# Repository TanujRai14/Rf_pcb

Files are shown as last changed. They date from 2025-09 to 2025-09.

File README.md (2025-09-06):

📡 STM32 + nRF24L01P USB Dongle (4-Layer PCB)

This project implements a USB-based transceiver dongle using the STM32L432 MCU and nRF24L01P RF module.
The board is designed as a 4-layer PCB optimized for USB high-speed signaling and RF performance.

🔧 Features

MCU: STM32L432KBU6 (Cortex-M4, USB support, low-power).

RF Transceiver: nRF24L01P with SMA antenna connector.

USB Interface: Micro USB-B with ESD protection.

Power Regulation: Onboard 3.3V regulator with USB +5V input.

Programming & Debugging: SWD connector for firmware upload/debug.

Clocking: 16 MHz crystal oscillator for the transceiver.

⚡️ PCB Design Notes

This design follows best practices for mixed-signal (USB + RF) high-speed boards:

4-Layer Stackup

Layer 1: Signal

Layer 2: Ground plane

Layer 3: Power plane + signal

Layer 4: Signal

➝ Provides controlled impedance routing and solid ground return paths.

USB Differential Pair

Routed as 90 Ω differential impedance.

Length matched using squiggle traces for proper signal timing.

Minimal via usage to reduce reflections.

Crystal Oscillator

No ground plane directly beneath the crystal to avoid damping oscillations.

RF Section

50 Ω controlled impedance routing to the SMA connector.

Antenna matching network (L-C components) placed close to RF pin.

Short traces and minimized via count for RF integrity.

Decoupling & Power Integrity

Multiple ceramic capacitors (100nF, 1µF, 10µF) placed near VDD pins.

Bulk capacitor on regulator output for stability.

Power traces kept short and wide to reduce IR drop.

Grounding

Continuous solid GND plane on Layer 2.

Stitching vias placed around high-speed and RF sections.

Segregation of analog/RF and digital sections to reduce noise coupling.

Other Notes

ESD protection diodes added on USB lines.

Reset capacitor for parasitic reset protection.

Careful placement of SWD pins for easy programming access.

🚀 Getting Started

Connect the board via USB Micro-B cable.

Flash firmware via SWD programmer (ST-Link, J-Link, etc.).

Use the USB interface for communication and debugging.

Attach an SMA antenna to nRF24L01P for wireless operation.

📌 To-Do / Future Improvements

 Add test points for power rails.

 Consider shielding can for RF section.

 Explore USB Type-C instead of Micro-B.

 Improve thermal relief on regulator section.

👤 Designer: Tanuj Rai
🛠 Tools Used: KiCad (schematic & PCB), 4-layer controlled impedance design.# Rf_pcb

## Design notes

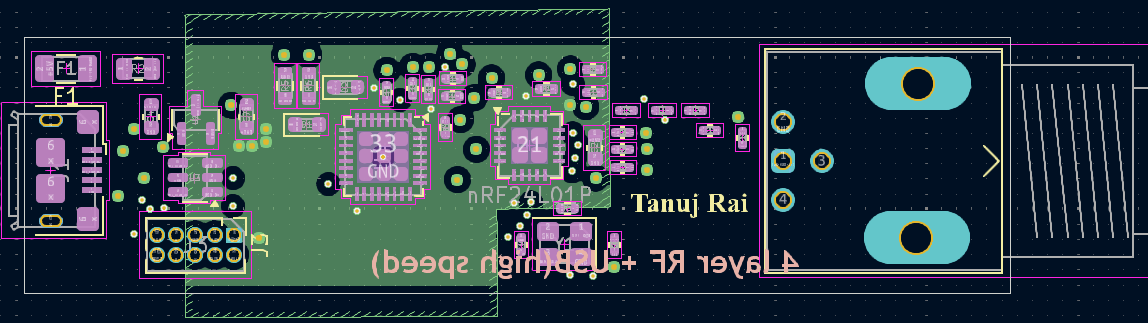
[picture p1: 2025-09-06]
Screenshot 2025-09-06 205455.png

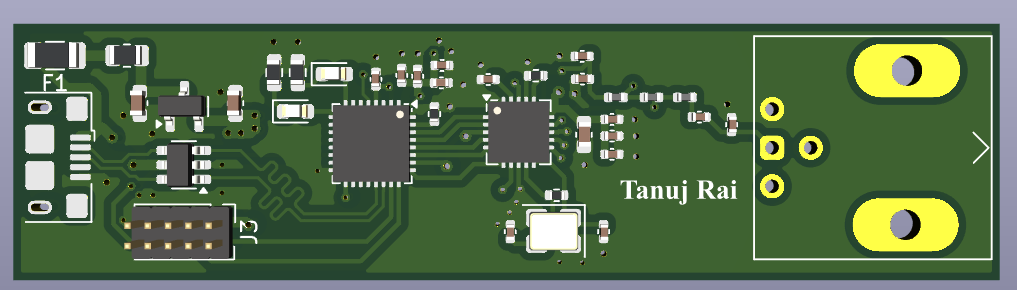
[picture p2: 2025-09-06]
Screenshot 2025-09-06 210044.png

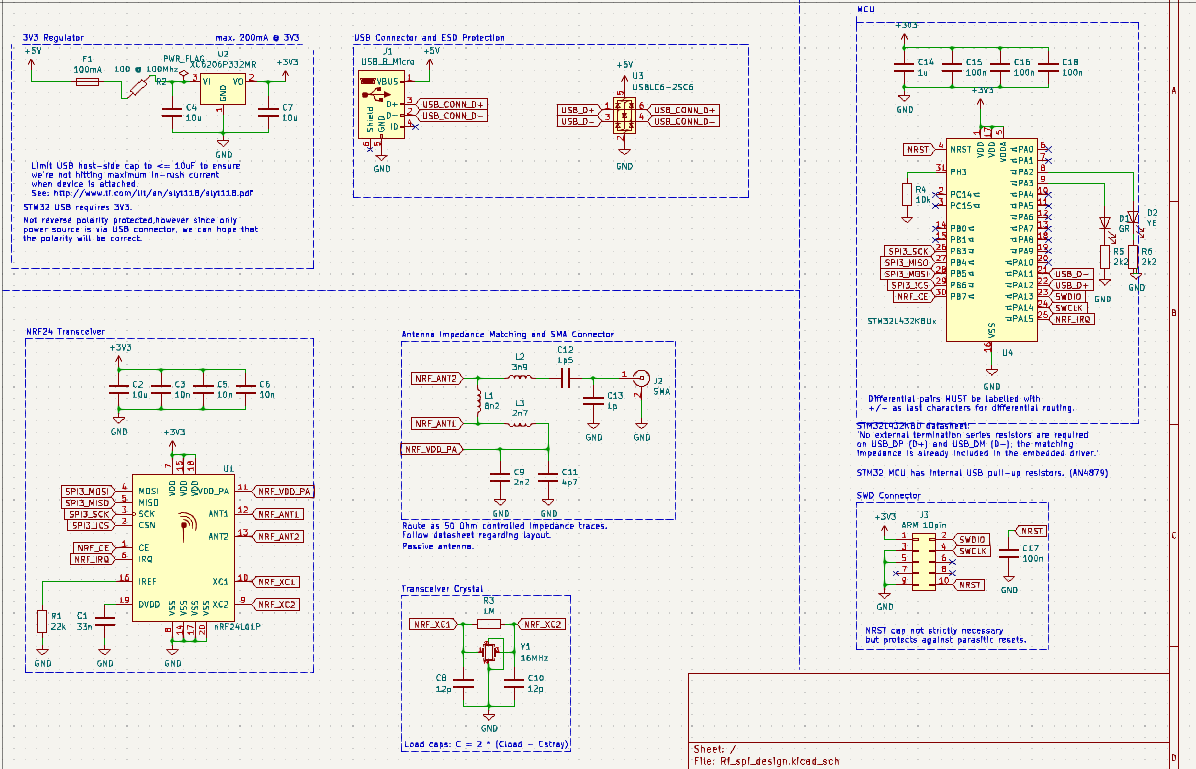
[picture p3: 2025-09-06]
Screenshot 2025-09-06 205347.png

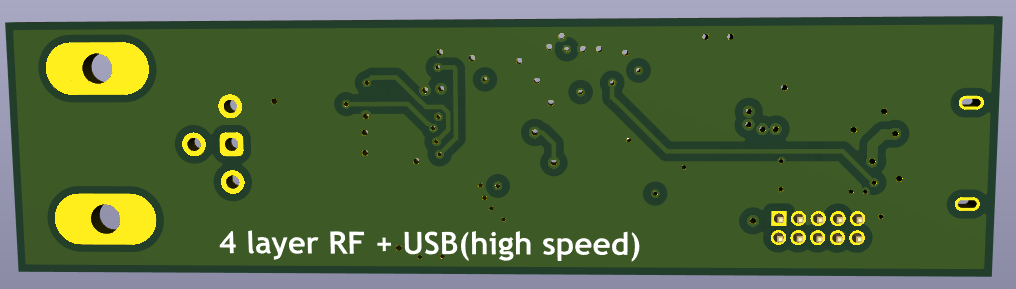
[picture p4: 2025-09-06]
Screenshot 2025-09-06 210100.png

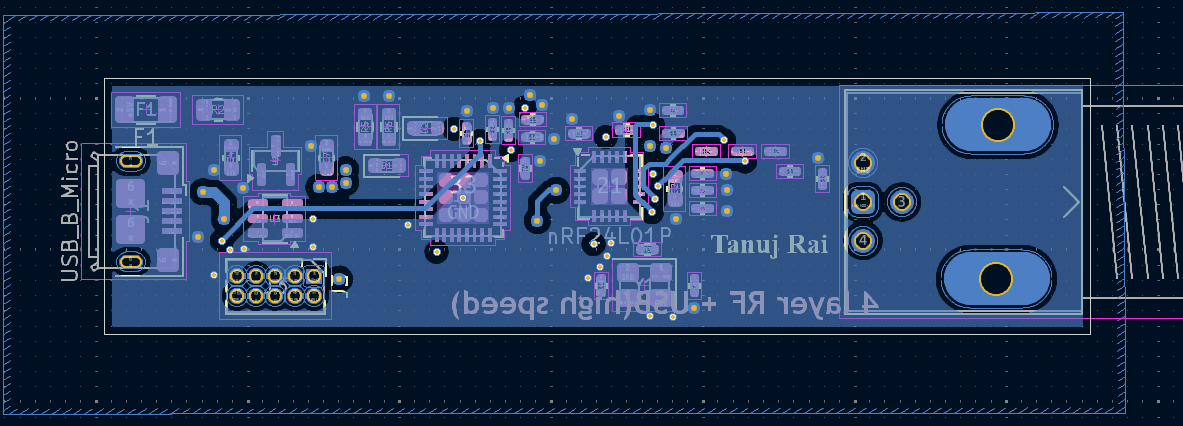
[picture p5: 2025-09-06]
Screenshot 2025-09-06 205516.png

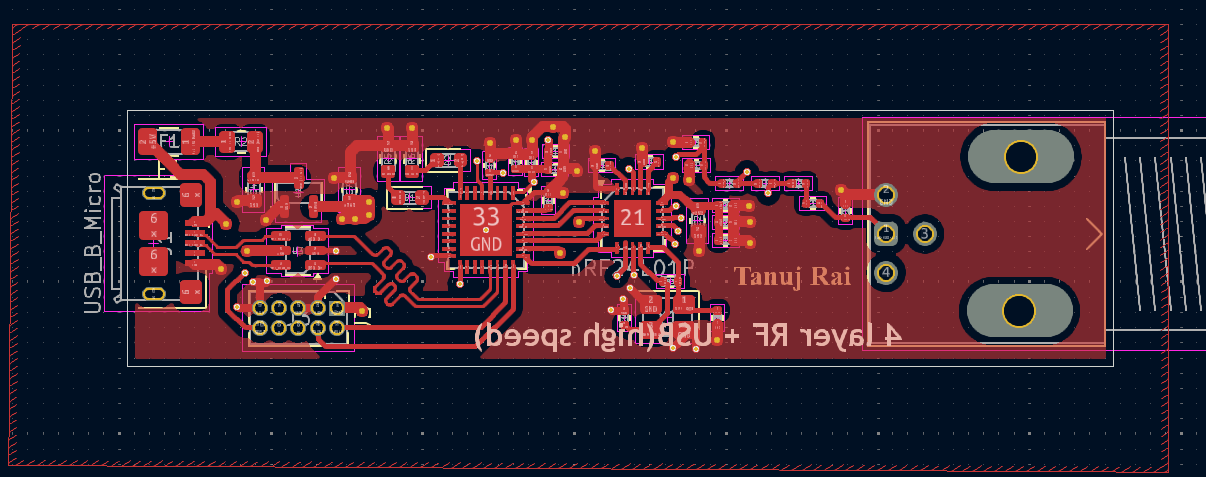
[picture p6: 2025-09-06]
Screenshot 2025-09-06 205444.png

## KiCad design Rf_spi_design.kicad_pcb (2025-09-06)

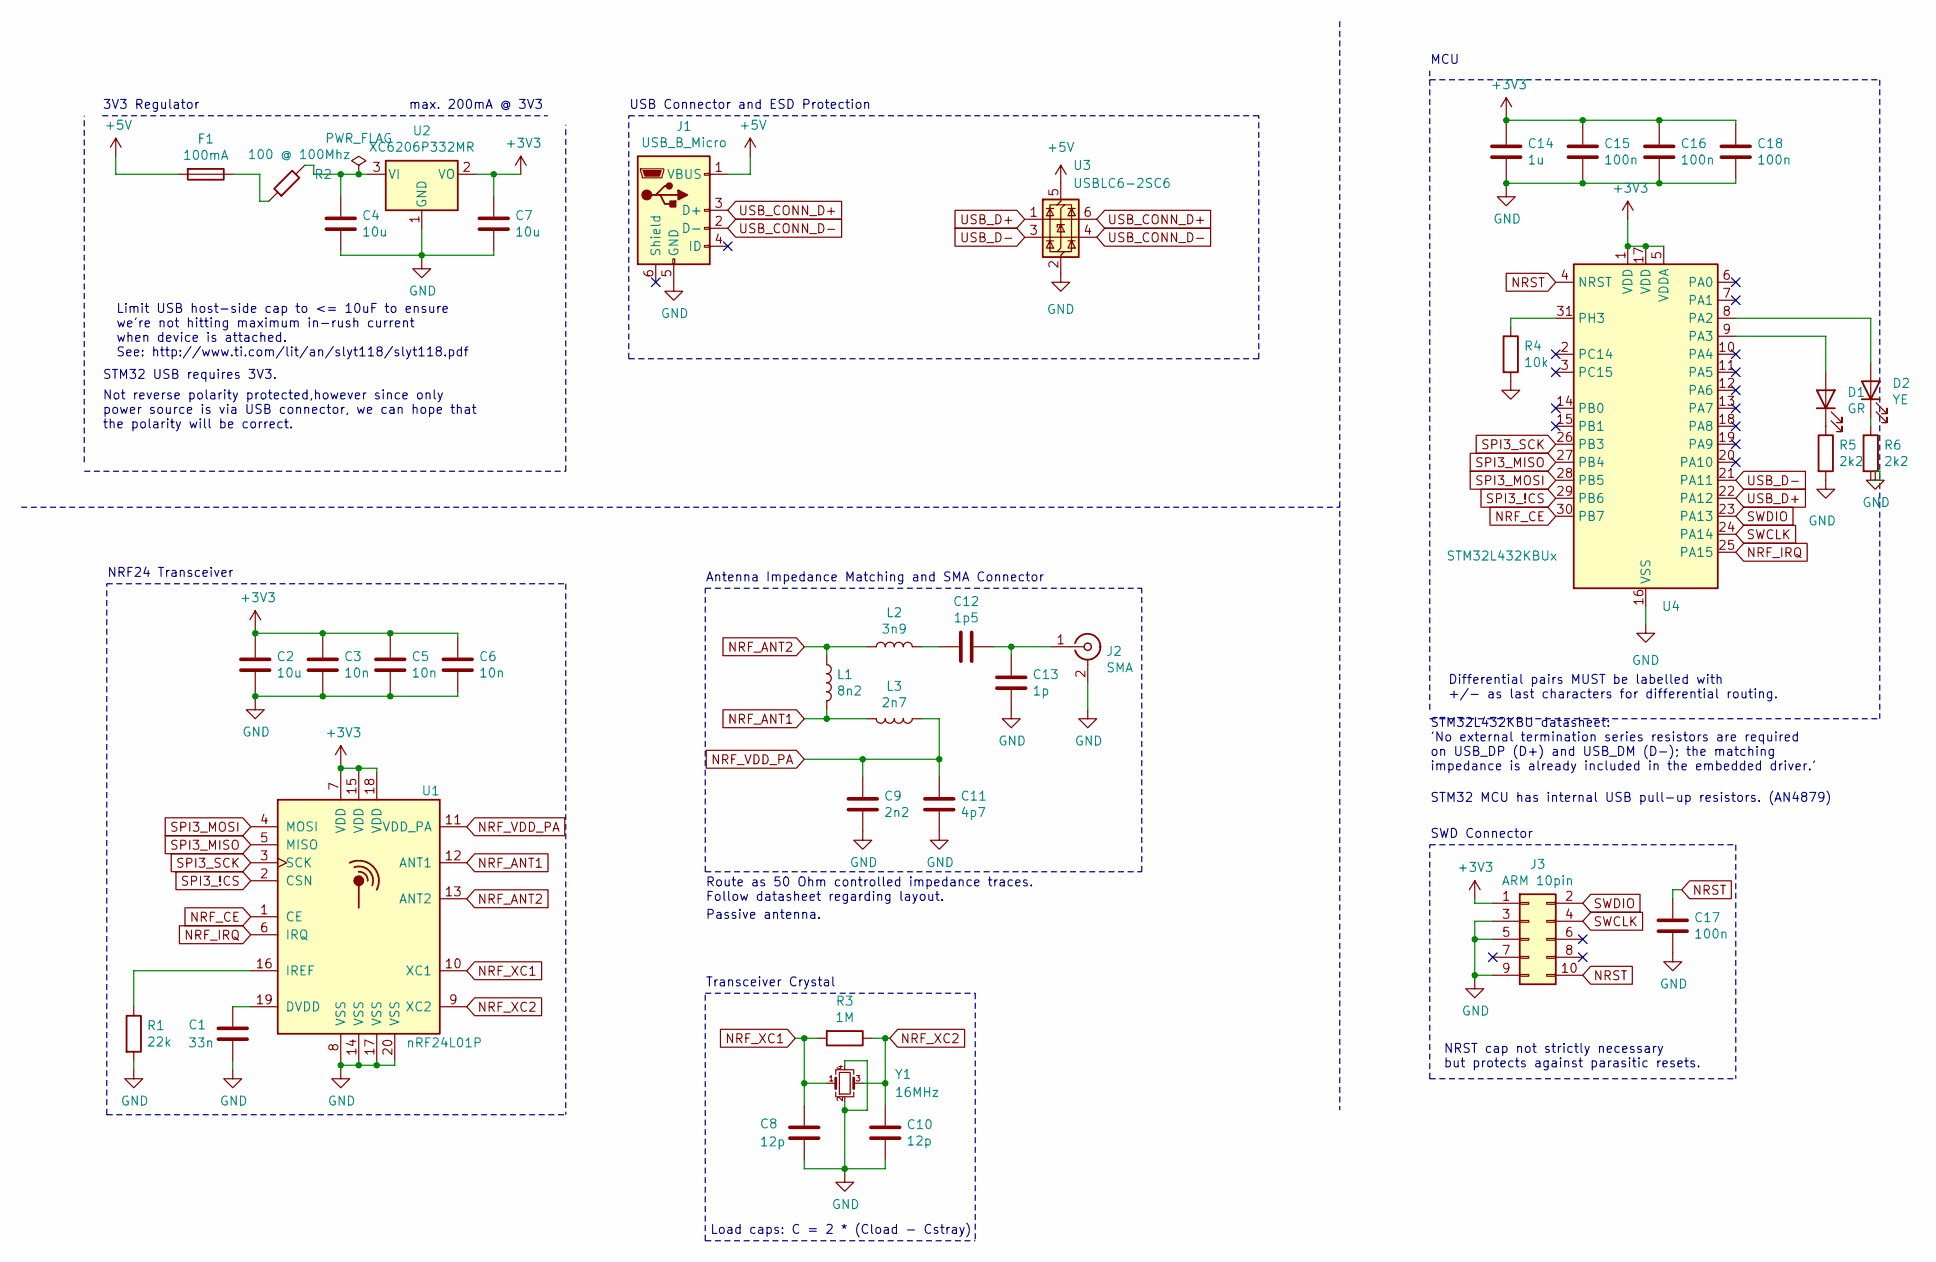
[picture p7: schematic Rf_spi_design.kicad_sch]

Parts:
C1: 33n; C_0402_1005Metric
C2, C4, C7: 10u; C_0603_1608Metric
C3, C5, C6: 10n; C_0402_1005Metric
C8, C10: 12p; C_0402_1005Metric
C9: 2n2; C_0402_1005Metric
C11: 4p7; C_0402_1005Metric
C12: 1p5; C_0402_1005Metric
C13: 1p; C_0402_1005Metric
C14: 1u; C_0402_1005Metric
C15, C16, C17, C18: 100n; C_0402_1005Metric
D1: GR; LED_0603_1608Metric
D2: YE; LED_0603_1608Metric
F1: 100mA; Fuse_1206_3216Metric
J1: USB_B_Micro; USB_Micro-B_Amphenol_10118193-0001LF_Horizontal
J2: SMA; BNC_Amphenol_031-6575_Horizontal
J3: ARM 10pin; PinHeader_2x05_P1.27mm_Vertical
L1: 8n2; L_0402_1005Metric
L2: 3n9; L_0402_1005Metric
L3: 2n7; L_0402_1005Metric
R1: 22k; R_0402_1005Metric
R2: 100 @ 100Mhz; R_0805_2012Metric
R3: 1M; R_0402_1005Metric
R4: 10k; R_0402_1005Metric
R5, R6: 2k2; R_0603_1608Metric
U1: nRF24L01P; QFN-20-1EP_4x4mm_P0.5mm_EP2.5x2.5mm
U2: XC6206P332MR; SOT-23
U3: USBLC6-2SC6; SOT-23-6
U4: STM32L432KBUx; QFN-32-1EP_5x5mm_P0.5mm_EP3.45x3.45mm
Y1: 16MHz; Crystal_SMD_3225-4Pin_3.2x2.5mm

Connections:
+3V3: C2.1, C3.1, C5.1, C6.1, C7.1, C14.1, C15.1, C16.1, C18.1, J3.1, U1.7 (VDD), U1.15 (VDD), U1.18 (VDD), U2.2 (VO), U4.1 (VDD), U4.5 (VDDA), U4.17 (VDD)
+5V: F1.2, J1.1 (VBUS), U3.5 (VBUS)
GND: C1.2, C2.2, C3.2, C4.2, C5.2, C6.2, C7.2, C8.2, C9.1, C10.2, C11.1, C13.1, C14.2, C15.2, C16.2, C17.2, C18.2, J1.5 (GND), J2.2 (Ext), J3.3, J3.5, J3.9, R1.2, R4.2, R5.2, R6.2, U1.8 (VSS), U1.14 (VSS), U1.17 (VSS), U1.20 (VSS), U2.1 (GND), U3.2 (GND), U4.16 (VSS), U4.32 (VSS), U4.33 (VSS), Y1.2, Y1.4
NRF_ANT1: L1.2, L3.2, U1.12 (ANT1)
NRF_ANT2: L1.1, L2.1, U1.13 (ANT2)
NRF_CE: U1.1 (CE), U4.30 (PB7)
NRF_IRQ: U1.6 (IRQ), U4.25 (PA15)
NRF_VDD_PA: C9.2, C11.2, L3.1, U1.11 (VDD_PA)
NRF_XC1: C8.1, R3.2, U1.10 (XC1), Y1.1
NRF_XC2: C10.1, R3.1, U1.9 (XC2), Y1.3
NRST: C17.1, J3.10, U4.4 (NRST)
unnamed: C12.2, L2.2
unnamed: D1.2 (A), U4.9 (PA3)
unnamed: D1.1 (K), R5.1
unnamed: D2.2 (A), U4.8 (PA2)
unnamed: D2.1 (K), R6.1
unnamed: F1.1, R2.1
unnamed: C12.1, C13.2, J2.1 (In)
unnamed: C1.1, U1.19 (DVDD)
unnamed: R1.1, U1.16 (IREF)
unnamed: C4.1, R2.2, U2.3 (VI)
unnamed: R4.1, U4.31 (PH3)
SPI3_!CS: U1.2 (CSN), U4.29 (PB6)
SPI3_MISO: U1.5 (MISO), U4.27 (PB4)
SPI3_MOSI: U1.4 (MOSI), U4.28 (PB5)
SPI3_SCK: U1.3 (SCK), U4.26 (PB3)
SWCLK: J3.4, U4.24 (PA14)
SWDIO: J3.2, U4.23 (PA13)
USB_CONN_D+: J1.3 (D+), U3.6 (I/O1)
USB_CONN_D-: J1.2 (D-), U3.4 (I/O2)
USB_D+: U3.1 (I/O1), U4.22 (PA12)
USB_D-: U3.3 (I/O2), U4.21 (PA11)

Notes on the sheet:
Differential pairs MUST be labelled with +/- as last characters for differential routing.
Not reverse polarity protected,however since only power source is via USB connector, we can hope that the polarity will be correct.
Passive antenna.
NRF24 Transceiver
Transceiver Crystal
STM32L432KBU datasheet: 'No external termination series resistors are required on USB_DP (D+) and USB_DM (D-); the matching impedance is already included in the embedded driver.'
3V3 Regulator
Antenna Impedance Matching and SMA Connector
Route as 50 Ohm controlled impedance traces. Follow datasheet regarding layout.
Load caps: C = 2 * (Cload - Cstray)
Limit USB host-side cap to <= 10uF to ensure we're not hitting maximum in-rush current when device is attached. See: http://www.ti.com/lit/an/slyt118/slyt118.pdf
SWD Connector
MCU
STM32 MCU has internal USB pull-up resistors. (AN4879)
NRST cap not strictly necessary but protects against parasitic resets.
max. 200mA @ 3V3
USB Connector and ESD Protection
STM32 USB requires 3V3.

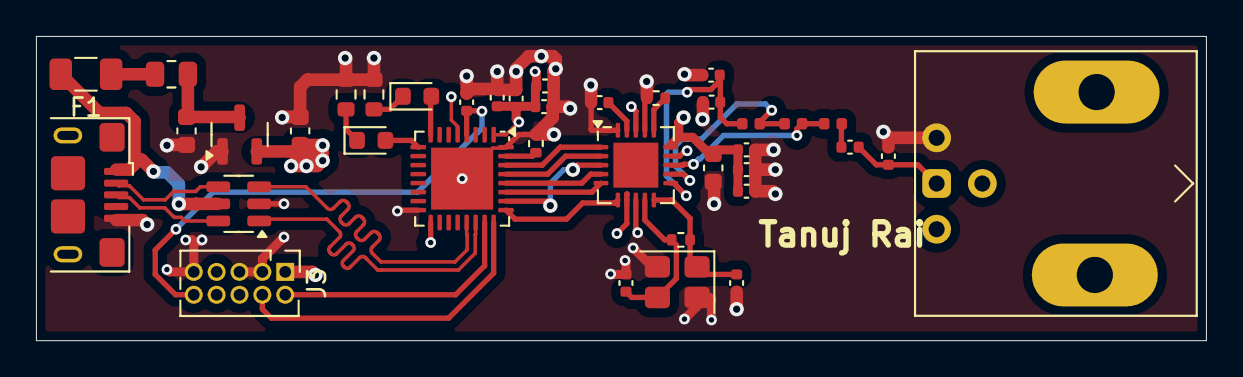
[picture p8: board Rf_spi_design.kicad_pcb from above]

Board: 4 copper layers, 65.0 x 16.9 mm, 38 parts (0 on the bottom side), 32 nets.
